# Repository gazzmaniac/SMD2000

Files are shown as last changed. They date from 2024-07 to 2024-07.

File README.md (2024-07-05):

# SMD2000
A mini-DTX version of the Amiga 2000 (motherboard)

## SMD 2000 Motherboard
This is the motherboard for the SMD2000 "BUSHFIRE" project, a mini-DTX sized Amiga 2000.
Official project information can be found at Amiga Retro Brisbane projects page:
https://www.amigaretro.com/projects/

## Licensing
Design is open source hardware.
1. Any and all derivative designs must also be open source.
2. No person, business, or other entity associated with this design shall be liable for any damages incurred by anyone as a result of using this design.  If you do not accept this condition do not build the project.
3. Free for private use by anyone.
4. Free for anyone to make for sale, except people associated with A1200.net keycaps.  You guys suck.
5. CERN Open Hardware Licence Version 2 - Strongly Reciprocal CERN-OHL-S) license applies, subject to conditions 1-4 above.
6. Any portions of this design from other projects shall be licensed according to their respective licenses if their licenses are not compatible with CERN-OHL-S or the conditions above.
7. All Other Rights Reserved.

## Requirements
To make this project work you also need to build an Agnus card and a CPU card.  They are documented separately.

Basic CPU card: https://github.com/gazzmaniac/SMD2000_cpu-card

2 MB Agnus card: https://github.com/gazzmaniac/SMD2000_Agnus2MB 

1 MB SMD Agnus card: https://github.com/gazzmaniac/SMD2000_Agnus_1MB 

1 MB TTH Agnus card: https://github.com/gazzmaniac/SMD2000_Agnus_1MB_TTH 

The SMD2000 project requires a donor Amiga, either an A500, A500+, A2000, or A600 plus a Gary.

## Useful Links
Bluster - in case you don't have a Buster IC (i.e. your donor machine is an A500):
https://github.com/LIV2/Bluster/tree/master
Bluster drop in replacement is not tested with the SMD2000 yet but there is no reason it will not work (the real Buster is confirmed working).

Open Video Hybrid - in case you don't have a Vidiot:
https://github.com/SukkoPera/OpenAmigaVideoHybrid

Latest RGB2HDMI software can be found at:
https://github.com/hoglet67/RGBtoHDMI/releases

## Notes and Eratta
Serial Port and Mouse Port are the same shape!  Now I know why Commodore used a 25 pin Serial port!  Be extra careful to not connect mouses to the serial port and serial devices to the mouse port otherwise there will be a release of magic smoke!  Recommend using DB9 protector for serial port e.g.: https://www.thingiverse.com/thing:2121877

### Power
Motherboard accepts a standard ATX PSU connector; both 20 and 24 pin versions work.  There is a header for a standard momentary push button switch which latches a 555 in bistable mode.  There is also a header to use a normal toggle switch or jumper to bypass the latching circuit and short PS_ON to GND.
The machine will happily run from a PicoPSU; the prototypes both ran from a PicoPSU-120-WI-25 powered from an old 19v laptop supply.  Just don't go connecting big loads like 5-1/4" hard disks to it.

### ROM
The SMD2000 has address lines for 1 MB or 2 MB ROMs.  Jumpers are present on the upper two address lines to switch between four 512 kb rom images (or two 1 MB images).

If using a Commodore rom or 27C400 eprom put it in the bottom of the socket, i.e. leave pins 1 and 42 on the socket empty (like on A500).  J519 & J520 do nothing in this scenario.

If using a 1 MB or 2 MB rom with multiple images you can switch between them using switches attached to CN519 & CN520; set J519 & J520 to 2-3.  Many users will want a switched Kickstart with KS1.3 and KS3.1/3.2; this can be achieved using a 27C800 with KS1.3 in the lower half and KS3.1 or 3.2 in the top half and connecting a switch to CN519.  You can switch up to four images (or a 1 MB image and two 512 kb images) using a 27C160 and CN520 as well.

If using a 1MB or 2MB custom rom set J519 & J520 to 1-2.

### LEDs
Extra LEDs have been added to the computer.  There are currently three ways to see the power LED, and two for the floppy drive LED (plus the LEDs on the floppy drives themselves).
Power LEDs:
Case: this is the same as in the A2000.  Populate Q302, R307, & C919.  If R308 is not populated the case LED will flash on and off instead of bright and dim when the Guru is about to meditate.  You can populate R308 if you want the LED to "dim" instead of switch off.  Commodore used a 200 ohm resistor in the A2000 and a 100 ohm resisitor on the A500 but optimal size will vary for your particular LED.
LED on motherboard: Populate Q360, R360, C360, & D360.  No "dim" option available.
LED on A500KBD port: fit Q361, R361, C361.  No "dim" option available.

### FDD LEDs
Floppy LEDs added same way as A500 (inverted _MTR0D).  Most users will not want to add a separate Floppy LED so these components are marked "Do Not Populate".
If using either of them populate the pull up resistor R363.
If using case floppy LED populate Q362, R362 & J360.
If using A500KBD port populate Q363 & R364.

NB the LEDs have changed since the final prototype.  The extra LED options (other than for the original case LED) are UNTESTED but there is no reason they will not work since it's simple copy paste.

### Other
Motherboard mounting holes had to be moved a little after the first prototype, and as a result the board was made 4 mm wider than "DTX" specification (on the slots side) but it still fits in the ML09 case.  Be careful if you intend to fit it in a tighter case.

## Fabrication Notes
Mouser part numbers for all components you can buy there are in the metadata for the symbols.  This has been exported as a CSV file, note this CSV file does not state which are Do Not Populate.

Use the interactive Bill of Materials for placing components, ibom.html.

The motherboard is expensive to make, being four layers.  I used JLCPCB, the cost was about $170 AUD for the minimum order of five boards, or a bit under $35 per board.  I chose green because it was the cheapest, they will do other colours for extra cost.  This includes an extra fee of $40 AUD due to the requirement for a 4-Wire Kelvin Test, due to the small size of the vias (this was mandatory from JLC).   Given the board is close to the limitations of JLCPCB I'm OK with that.  Don't specify the Kelvin test at initial checkout, they will add it later.  Even if you do specify it at checkout they will add it later again and you will pay for it twice (you can guess how I know this).  Even with the paying for two Kelvin tests it's way cheaper than PCBWaaaaaaay at USD 187 (about $280 AUD).

Assembly of the motherboard is a lot of work.  You can get JLC to partially assemble the board, I paid $284 AUD for partial assembly of two boards for the first prototype and $450 to partially assemble all five of the second prototype - that's most of the 0805 sized "birdseed" passives, about half the SMD ICs, and most of the headers.  That cost includes $30-40 worth of components on each board which you have to buy anyway, so it's actually a bargain if you consider it in relation to your hourly rate.  Get some mates together to share the upfront cost.  I think it's worthwhile unless you really, really like soldering birdseed.
I've added JLC's part number as a field in Kicad for many of the components so it shows up in their BOM tool, but it's not there for every component, and you will have to do some substitutions since the project was set up to be predominantly purchased from Mouser (I was going to hand solder it), some stuff is out of stock at JLC, and some stuff simply isn't available like the edge connectors.  When you use JLC's tool make sure you save a PDF copy of the BOM page so you know what not to buy from Mouser.  Also be aware if you want two sided assembly they will want you to add rails to the board, make sure they add a v cut so you can break them off after.  It's easier to specify this at the time of order.

This is a self-funded project and none of the companies mentioned have paid me anything.  This information is simply for your information, you can buy your PCB and component from whoever you like.

Finally, I had dramas with the tiny resistor packs every time I had to install them.  They're a real pain in the bum to solder by hand, and because JLC didn't have most of them in stock so I had to do it myself.  If your board doesn't work straight away, try reflowing all the resisitor packs.  If your mouse doesn't move check the resistor packs.  If you're cracking the shits it's probably because of the resistor packs.  You get the picture.  If you have a microscope it's really useful to check each one as you go.

## 3D Prints
An IO plate for the motherboard included.  Includes space for all the connectors on the back of the motherboard, plus parallel,  joystick, HDMI, and the Pi Button.

There is also a print for a bracket to hold a gotek and the power connector for a PicoPSU that fits in the spot for an SFX PSU.  It's tight, you'll probably need to change the right angle 34 pin and berg connectors for vertical connectors.

Photos of both are below, apologies for the print quality of the gotek bracket, I will update with a picture of a better quality print when I have time to print one.

FreeCad (v0.20.1) files are included so feel free to modify as needed.





## References
### Commodore Amiga References

Commodore Amiga A500/A2000 Technical Reference Manual.

Commodore schematics for A2000 Rev 4 & Rev 6.2, A500 Rev 6 & Rev 8 (A500+), and A1200 R1D4 schematics.  Scanned originals and amigawiki.org vector schematics referenced.

Coprocessor Expansion and 86 Pin Signals on Amiga Computers by Dave Haynie; this is presumably a Commodore document.

### Other References
DTX Mechanical Interface Specification rev 1.0.

ATX Specification v2.1 & v2.2.

Intel ISA Bus Specification and Application Notes.

Silverstone (r) ML109 case datasheet, www.silverstonetek.com.

### Other Projects incorporated into this one
#### RGB2HDMI
https://github.com/c0pperdragon/Amiga-Digital-Video

https://github.com/Bloodmosher/Amiga-VideoSlot-RGBtoHDMI

#### Video Output
https://www.pcbway.com/project/shareproject/Commodore_Amiga_DB23_RGB_External_Video_Buffer_V6_Compatible_with_GBS_8200_822_00cf763f.html

### Symbols
Symbols and footprints for most parts were downloaded from Mouser/Samacsys, and most were modified to make the schematics more readable.  Samacsys parts probably aren't covered by the Open Source license.  

Footprints and symbols for generic parts e.g. jumpers/headers use Kicad libraries. 

Most of the Amiga specific parts were modified from my SMD500 project.

### Datasheets
Links to datasheets are in the symbol metadata.

VGA Pinout Guide, https://pinoutguide.com/Video/VGA15_pinout.shtml.

M27C400 & M27C800 EPROM data sheets.

SPC Multicomp DSub9 to DSub25 adapter, http://www.farnell.com.

### Technical Guides
CTS Corporation Application Note: Crystal Basics, CTS Corporation.

A Guide to Debouncing by Jack G. Ganssle © 2004 The Ganssle Group.

555 timer in monostable mode https://todbot.com/blog/2010/01/02/momentary-button-as-onoff-toggle-using-555/.

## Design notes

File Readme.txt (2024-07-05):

SMD 2000 Motherboard
*-----------------------------------------------------------------------------*
This is the motherboard for the SMD2000 "BUSHFIRE" project, a mini-DTX sized Amiga 2000.
Official project information can be found at Amiga Retro Brisbane projects page:
https://www.amigaretro.com/projects/

Licensing
*-----------------------------------------------------------------------------*
LICENSING:
Design is open source hardware.
1. Any and all derivative designs must also be open source.
2. No person, business, or other entity associated with this design shall be liable for any damages incurred by anyone as a result of using this design.  If you do not accept this condition do not build the project.
3. Free for private use by anyone.
4. Free for anyone to make for sale, except people associated with A1200.net keycaps.  You guys suck.
5. CERN Open Hardware Licence Version 2 - Strongly Reciprocal CERN-OHL-S) license applies, subject to conditions 1-4 above.
6. Any portions of this design from other projects shall be licensed according to their respective licenses if their licenses are not compatible with CERN-OHL-S or the conditions above.
7. All Other Rights Reserved.

Requirements
*-----------------------------------------------------------------------------*
To make this project work you also need to build an Agnus card and a CPU card.  They are documented separately.

The SMD2000 project requires a donor Amiga, either an A500, A500+, A2000, or A600 plus a Gary.

Useful Links
*-----------------------------------------------------------------------------*
Bluster - in case you don't have a Buster IC (i.e. your donor machine is an A500):
https://github.com/LIV2/Bluster/tree/master
Bluster drop in replacement is not tested with the SMD2000 yet (the real Buster is).

Open Video Hybrid - in case you don't have a Vidiot:
https://github.com/SukkoPera/OpenAmigaVideoHybrid

Latest RGB2HDMI software can be found at:
https://github.com/hoglet67/RGBtoHDMI/releases

Notes and Eratta
*-----------------------------------------------------------------------------*
Serial Port and Mouse Port are the same shape!  Now I know why Commodore used a 25 pin Serial port!  Be extra careful to not connect mouses to the serial port and serial devices to the mouse port otherwise there will be release of magic smoke!  Recommend using DB9 protector for serial port e.g.: https://www.thingiverse.com/thing:2121877

ROM:
A2000 rom socket is a 40 pin socket and can take a 512 kB rom 
(27C400 equivalent).

The SMD2000 ROM socket is a 42 pin socket wired for a 1MB or 2 MB rom (e.g. 27C800).  Pins are offset by 1, since extra address lines wired to CPU Bus A19 & A20 (this is normal for EPROMs).  

If using a Commodore rom or 27C400 eprom put it in the bottom of the socket, i.e. leave pins 1 and 42 on the socket empty (like on A500).  J519 & J520 do nothing.

If using a 1 MB or 2 MB rom with multiple images you can switch them using switches attached to CN519 & CN520; set J519 & J520 to 2-3.  Many users want a Kickstart switch with KS1.3 and KS3.1/3.2; this can be achieved using a 27C800 with KS1.3 in the lower half and KS3.1 or 3.2 in the top half and connecting a switch to CN519.

If using a 1MB or 2MB custom rom set J519 & J520 to 1-2.

LEDs:
LEDs have been added to the computer.  There are currently three ways to see the power LED, and two for the floppy drive LED (plus the LEDs on the floppy drives themselves).
Power LEDs:
Case: this is the same as in the A2000.  Populate Q302, R307, & C919.  If R308 is not populated the case LED will flash on and off instead of bright and dim when the Guru is about to meditate.  You can populate R308 if you want the LED to "dim" instead of switch off.  Commodore used a 200 ohm resistor in the A2000 and a 100 ohm resisitor on the A500 but optimal size will vary for each LED.
LED on motherboard: Populate Q360, R360, C360, & D360.  No "dim" option available.
LED on A500KBD port: fit Q361, R361, C361.  No "dim" option available.

FDD LEDs:
Floppy LEDs added same way as A500 (inverted _MTR0D).  Most users will not want to add a Floppy LED to the case so these components are marked "Do Not Populate".
If using either of them populate the pull up resistor R363.
If using case floppy LED populate Q362, R362 & J360.
If using A500KBD port populate Q363 & R364.

NB the LEDs have changed since the prototype.  The extra LED options (other than for the case LED) are UNTESTED but there is no reason they will not work.

Motherboard mounting holes had to be moved a little after the first prototype, and as a result the board was made 4 mm wider than "DTX" specification but it still fits in the ML09 case.  Be careful if you intend to fit it in a tighter case.

Fabrication Notes
*-----------------------------------------------------------------------------*
Mouser part numbers for all components you can buy there are in the metadata for the symbols.  This has been exported as a CSV file, note this CSV file does not state which are Do Not Populate.

Use the interactive Bill of Materials for placing components, ibom.html.

The motherboard is expensive to make, being four layers.  I used JLCPCB, the cost was about $170 AUD for the minimum order of five boards, or a bit under $35 per board.  I chose green because it was the cheapest, they will do other colours for extra cost.  This includes an extra fee of $40 AUD due to the requirement for a 4-Wire Kelvin Test, due to the small size of the vias (this was mandatory from JLC).   Given the board is close to the limitations of JLCPCB I'm OK with that.  Even with the Kelvin testing it's less than half the price of PCBWaaaaaaay at USD 187.

Assembly of the motherboard is a lot of work.  You can get JLC to partially assemble the board, I paid $284 AUD for partial assembly of two boards for the first prototype and $450 to partially assemble all five of the second prototype - that's most of the 0805 sized "birdseed" passives, about half the SMD ICs, and most of the headers.  That cost includes $30-40 worth of components on each board which you have to buy anyway, so it's actually a bargain if you consider it in relation to your hourly rate.  Get some mates together to share the upfront cost.  I think it's worthwhile unless you really, really like soldering birdseed.
I've added JLC's part number as a field in Kicad for many of the components so it shows up in their BOM tool, but it's not there for every component, and you will have to do some substitutions since the project was set up to be predominantly purchased from Mouser (I was going to hand solder it), and some stuff simply isn't available like the edge connectors.  If you do use JLC's tool make sure you save a PDF copy of the BOM page so you know what not to buy from Mouser.  Also be aware if you want two sided assembly they will want you to add rails to the board, make sure they add a v cut so you can break them off after.  It's easier to specify this at the time of order.

This is a self-funded project and none of the companies mentioned have paid me anything.  This information is simply for your information, you can buy your PCB and component from whoever you like.

Finally, I had dramas with the tiny resistor packs every time I had to install them.  They're a real pain in the bum to solder by hand, and JLC didn't have most of them in stock so I had to do it myself.  If your board doesn't work straight away, try reflowing all the resisitor packs.  If your mouse doesn't move check the resistor packs.  If you're cracking the shits it's probably because of the resistor packs.  You get the picture.  If you have a microscope it's really useful to check each one as you go.

References
*-----------------------------------------------------------------------------*
Commodore Amiga References:
Commodore Amiga A500/A2000 Technical Reference Manual.
Commodore schematics for A2000 Rev 4 & Rev 6.2, A500 Rev 6 & Rev 8 (A500+), and A1200 R1D4 schematics.  Scanned originals and amigawiki.org rebuilds referenced.
Coprocessor Expansion and 86 Pin Signals on Amiga Computers by Dave Haynie; this is presumably a Commodore document.

Other References:
DTX Mechanical Interface Specification rev 1.0.
ATX Specification v2.1 & v2.2.
Intel ISA Bus Specification and Application Notes.
Silverstone (r) ML109 case datasheet, www.silverstonetek.com.

Other Projects incorporated into this one:
RGB2HDMI:
https://github.com/c0pperdragon/Amiga-Digital-Video
https://github.com/Bloodmosher/Amiga-VideoSlot-RGBtoHDMI
Video Output:
https://www.pcbway.com/project/shareproject/Commodore_Amiga_DB23_RGB_External_Video
  _Buffer_V6_Compatible_with_GBS_8200_822_00cf763f.html

Symbols:
Symbols and footprints for most parts were downloaded from Mouser/Samacsys, and most were modified to make the schematics more readable.  Samacsys parts probably aren't covered by the Open Source license.  Footprints and symbols for generic parts e.g. jumpers/headers use Kicad libraries. 

Datasheets:
Links to datasheets are in the symbol metadata.
VGA Pinout Guide, https://pinoutguide.com/Video/VGA15_pinout.shtml.
M27C400 & M27C800 EPROM data sheets.
SPC Multicomp DSub9 to DSub25 adapter, http://www.farnell.com.

Technical Guides:
CTS Corporation Application Note: Crystal Basics, CTS Corporation.
A Guide to Debouncing by Jack G. Ganssle © 2004 The Ganssle Group.
555 timer in monostable mode https://todbot.com/blog/2010/01/02/momentary-button-as-onoff-toggle-using-555/.

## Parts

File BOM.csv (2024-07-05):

Additional Parts (Not Mouser). Delete this section for upload to Mouser
Reference | Value | Footprint | Datasheet | Comment | Description | EU_RoHS_Compliance | Height | LCSC Part # | Manufacturer_Name | Manufacturer_Part_Number | Modified | Mouser Part Number | Mouser Price/Stock | Qty
HY200 | VIDIOT |  |  |  | Video Hybrid |  |  |  | MOS Technology | 390229-0x |  |  |  | 1
U102 | GARY |  |  |  | 5719 |  |  |  | MOS Technology | 318072-01 |  |  |  | 1
U200 | PAULA |  |  |  | 8364R7 |  |  |  | MOS Technology | 252127-02 |  |  |  | 1
U201 | DENISE |  |  |  | 8362/8373 |  |  |  | MOS Technology | 252126-02/390433-02 |  |  |  | 1
U800 | BUSTER |  |  |  | 5731 |  |  |  | MOS Technology | 318075-02 |  |  |  | 1
U300, U301 | CIA |  |  |  | 8520A-1 |  |  |  | MOS Technology | 391078-0x |  |  |  | 2
U500 | ROM |  |  |  | 27C400 |  |  |  | Various |  |  |  |  | 1
U801 | MSM6242 |  | https://pdf1.alldatasheet.com/datasheet-pdf/download/11259/OKI/MSM6242B.html |  | Real Time Clock |  |  |  | OKI | MSM6242 |  |  |  | 1
Reference | Value | Footprint | Datasheet | Comment | Description | EU_RoHS_Compliance | Height | LCSC Part # | Manufacturer_Name | Manufacturer_Part_Number | Modified | Mouser Part Number | Mouser Price/Stock | Qty
BT800 | CR1220 | SMD2000_Footprints:S8411-45R_1 | https://cdn.harwin.com/pdfs/S8411R.pdf |  |  |  |  | C9900008699 | Harwin | S8411-45R |  | 855-S8411-45R | https://www.mouser.co.uk/ProductDetail/Harwin/S8411-45R?qs=Qom7kyPojXY6B0JhnWxDgQ%3D%3D | 1
C101, C222, C223, C402-C406, C408, C412, C420-C422, C471 | 47 uF | SMD2000_Footprints:EEE0GA101SR | http://industrial.panasonic.com/cdbs/www-data/pdf/RDE0000/ABA0000C1142.pdf |  | Cap Aluminum Lytic 47uF 16V 20% (5 X 5.4mm) SMD 39mA 1000h 85C Automotive T/R |  | 6.5 | C178500 | Panasonic | EEE-1CA470WAR |  | 667-EEE-1CA470WAR | https://www.mouser.co.uk/ProductDetail/Panasonic/EEE-1CA470WAR?qs=d1CqaRUMZD%2FiYn4JMv7QWw%3D%3D | 14
C102-C108, C200, C202, C203, C205, C206, C230, C234, C240, C244, C300-C303, C305, C351, C360, C361, C450, C451, C600-C605, C607, C800, C802-C805, C812, C815, C900, C901, C903, C906, C909, C910, C915, C916, C918, C919, C1201-C1205, C1251 | 0.1 uF | Capacitor_SMD:C_0805_2012Metric_Pad1.18x1.45mm_HandSolder | http://datasheets.avx.com/X7RDielectric.pdf |  | 0805 X7R ceramic capacitor,100nF 50V AVX 0805 Standard 100nF Ceramic Multilayer Capacitor, 50 V dc, +125degC, X7R Dielectric, /-10% SMD |  | 0.94 | C123316 | AVX | 08055C104KAT2A |  | 581-08055C104K | https://www.mouser.co.uk/ProductDetail/AVX/08055C104KAT2A?qs=2ujN4bDBNE9mJvapP%252BjopA%3D%3D | 56
C201, C219-C221, C500 | 0.22uF | Capacitor_SMD:C_0805_2012Metric_Pad1.18x1.45mm_HandSolder | http://datasheets.avx.com/X7RDielectric.pdf |  | 0805 X7R ceramic capacitor,0.22uF 50V AVX 0805 Standard 100nF Ceramic Multilayer Capacitor, 50 V dc, +125degC, X7R Dielectric, /-10% SMD |  | 0.94 |  | AVX | 08053C224K4T2A |  | 581-08053C224K4T2A | https://au.mouser.com/ProductDetail/KYOCERA-AVX/08053C224K4T2A?qs=MaXcIz3NWU%252Bt3orNT4zafw%3D%3D | 5
C204, C401, C407, C409, C413, C472 | 0.01 uF | Capacitor_SMD:C_0805_2012Metric_Pad1.18x1.45mm_HandSolder | https://componentsearchengine.com/Datasheets/1/0805YC473KAT2A.pdf |  | Capacitor 0805 0.01UF +/-10% 16V |  |  |  | AVX | 0805YC103KAT4A |  | 581-0805YC103KAT4A | https://au.mouser.com/ProductDetail/KYOCERA-AVX/0805YC103KAT4A?qs=0j3vzYx9OgSOvplKldyO1Q%3D%3D | 6
C210-C213 | 0.047 uF | Capacitor_SMD:C_0805_2012Metric_Pad1.18x1.45mm_HandSolder | https://componentsearchengine.com/Datasheets/1/0805YC473KAT2A.pdf |  | Capacitor 0805 0.047UF +/-10% 16V |  |  |  | AVX | 0805YC473KAT2A |  | 581-0805YC473K | https://www.mouser.com/Search/Refine.aspx?Keyword=581-0805YC473K | 4
C214, C225, C226, C912 | 470 uF | SMD2000_Footprints:EEE-1EA471UAP | http://industrial.panasonic.com/cdbs/www-data/pdf/RDE0000/ABA0000C1142.pdf |  | PANASONIC - EEE-1EA471UAP - SMD Aluminum Electrolytic Capacitor, Radial Can - SMD, 470 F, 25 V, S Series, 2000 hours @ 85C |  |  | C336541 | Panasonic | EEE-1EA471UAP |  | 667-EEE-1EA471UAP | https://www.mouser.co.uk/ProductDetail/Panasonic/EEE-1EA471UAP?qs=d1CqaRUMZD8omPdhpIp4IQ%3D%3D | 4
C224, C415, C811 | 4.7 uF | SMD2000_Footprints:EEE1AA220WR | http://industrial.panasonic.com/cdbs/www-data/pdf/RDE0000/ABA0000C1142.pdf |  | Cap Aluminum Lytic 4.7uF 50V 20% (4 X 5.4mm) SMD 18mA 1000h 85C Automotive T/R |  | 5.5 | C336729 | Panasonic | EEE-1HA4R7WAR |  | 667-EEE-1HA4R7WAR | https://au.mouser.com/ProductDetail/Panasonic/EEE-1HA4R7WAR?qs=d1CqaRUMZD%2FQfKz6dMeWdw%3D%3D | 3
C231, C241 | 6800 pF | Capacitor_SMD:C_0805_2012Metric_Pad1.18x1.45mm_HandSolder |  |  | Multilayer Ceramic Capacitors MLCC - SMD/SMT 50V 6800pF X7R 0805 10% Tol |  | 0.94 | C597425 | AVX | 08055C682KAT2A |  | 581-08055C682K | https://www.mouser.co.uk/ProductDetail/AVX/08055C682KAT2A?qs=wrGVMSTfBskTBQdegZmEHA%3D%3D | 2
C232, C242 | 3900 pF | Capacitor_SMD:C_0805_2012Metric_Pad1.18x1.45mm_HandSolder | https://www.arrow.com/en/products/08055c392kat2a/avx |  | Cap Ceramic 0.0039uF 50V X7R 10% Pad SMD 0805 125C T/R |  | 0.94 | C2181318 | AVX | 08055C392KAT2A |  | 581-08055C392K | https://www.mouser.co.uk/ProductDetail/AVX/08055C392KAT2A?qs=FObrNSbSblfLejKoKFqNfg%3D%3D | 2
C233, C243, C813, C814, C1206 | 22 uF | SMD2000_Footprints:EEE0GA101SR | https://componentsearchengine.com/Datasheets/1/EEE-1VA220WAR.pdf |  | Cap Aluminum Lytic 22uF 35V 20% (5 X 5.4mm) SMD 36mA 1000h 85C Automotive T/R |  | 6.5 | C336455 | Panasonic | EEE-1VA220WAR |  | 667-EEE-1VA220WAR | https://www.mouser.com/Search/Refine.aspx?Keyword=667-EEE-1VA220WAR | 5
C259-C261, C904, C905, C907, C914, C920 | 100 pF | Capacitor_SMD:C_0805_2012Metric_Pad1.18x1.45mm_HandSolder | https://componentsearchengine.com/Datasheets/1/06031A100FAT2A.pdf |  | 0805 C0G ceramic capacitor,100pF 50V AVX 0805 Standard 100pF Ceramic Multilayer Capacitor, 50 V dc C0G Dielectric +/-5% SMD |  | 0.94 | C2167403 | AVX | 08055A101JAT2A |  | 581-08055A101J | https://www.mouser.co.uk/ProductDetail/AVX/08055A101JAT2A?qs=o9qE778H9QGBR%2FfSpI%2FCIw%3D%3D | 8
C350 | 1 uF | Capacitor_SMD:C_0805_2012Metric_Pad1.18x1.45mm_HandSolder | https://componentsearchengine.com/Datasheets/2/08055C105KAT2A.pdf |  | MLCC Capacitor 1uF 0805 X7R 10% 50V AVX 0805 Standard 1uF Ceramic Multilayer Capacitor, 50 V, +125C, X7R Dielectric, +/-10% |  | 1.4 | C2167382 | AVX | 08055C105KAT2A |  | 581-08055C105KAT2A | https://www.mouser.co.uk/ProductDetail/AVX/08055C105KAT2A?qs=2ujN4bDBNE9BNQHBgLvfKA%3D%3D | 1
C400, C416, C470 | 220 uF | SMD2000_Footprints:EEHZT1E331UP | https://componentsearchengine.com/Datasheets/1/EEE-1EA221UAP.pdf |  | Panasonic 220F 25V dc Aluminium Electrolytic Capacitor, Surface Mount 8 x 10.2mm +85C 8mm 10.2mm |  | 10.8 | C336328 | Panasonic | EEE-1EA221UAP |  | 667-EEE-1EA221UAP | https://www.mouser.com/Search/Refine.aspx?Keyword=667-EEE-1EA221UAP | 3
C452 | 4.7 uF | Capacitor_SMD:C_0805_2012Metric_Pad1.18x1.45mm_HandSolder | https://au.mouser.com/datasheet/2/40/KGM_X7R-3223212.pdf |  | Multilayer Ceramic Capacitors MLCC - SMD/SMT KGM21AR71E475KU NEW GLOBAL PN 25V 4.7uF X7R 0805 10% |  | 1.4 |  | AVX | 08053C475KAT2A |  | 581-08053C475KAT2A | https://au.mouser.com/ProductDetail/KYOCERA-AVX/08053C475KAT2A?qs=ZBeOGGPQgEF8AwTFFr2g8w%3D%3D | 1
C460, C461 | 10 uF | SMD2000_Footprints:EEE1AA220WR | http://industrial.panasonic.com/cdbs/www-data/pdf/RDE0000/ABA0000C1142.pdf |  | PANASONIC ELECTRONIC COMPONENTS - EEE1EA100WAR - CAP, ALU ELEC, 10UF, 25V, SMD |  | 5.5 | C336730 | Panasonic | EEE-1EA100WAR |  | 667-EEE-1EA100WAR | https://www.mouser.co.uk/ProductDetail/Panasonic/EEE-1EA100WAR?qs=d1CqaRUMZD8IzJai8yeTmQ%3D%3D | 2
C617, C619-C633, C635, C637, C639, C641, C645, C647, C649-C652, C654, C655, C657-C674, C678 | 1000 pF | Capacitor_SMD:C_0805_2012Metric_Pad1.18x1.45mm_HandSolder | https://spicat.kyocera-avx.com/product/mlcc/chartview/08055C102KAT2A/DataSheet/X7R |  | 0805 X7R ceramic capacitor,1nF 50V AVX 0805 Standard 1nF Ceramic Multilayer Capacitor, 50 V dc, +125C, X7R Dielectric, +/-10% SMD |  | 0.94 | C2167121 | AVX | 08055C102KAT2A |  | 581-08055C102K | https://www.mouser.co.uk/ProductDetail/AVX/08055C102KAT2A?qs=m1SnNO%2FH6BdUeLRSfRyJzA%3D%3D | 47
C810 | 18 pF | Capacitor_SMD:C_0805_2012Metric_Pad1.18x1.45mm_HandSolder | https://componentsearchengine.com/Datasheets/1/08055A180KAT4A.pdf |  | Capacitor, 0805 18pF +/-10% 50V |  |  | C2209310 | AVX | 08055A180KAT4A |  | 581-08055A180KAT4A | https://www.mouser.com/Search/Refine.aspx?Keyword=581-08055A180KAT4A | 1
C908, C913, C1252 | 47 pF | Capacitor_SMD:C_0805_2012Metric_Pad1.18x1.45mm_HandSolder | https://au.mouser.com/datasheet/2/40/C0GNP0_KGM-3216332.pdf |  | Capacitor, 0805 47pF +/-10% 50V |  |  | C2209271 | AVX | 08055A470KAT4A |  | 581-08055A470KAT4A | https://au.mouser.com/ProductDetail/KYOCERA-AVX/08055A470KAT4A?qs=puY0Jq7LBATPo1cS1%252BxjXg%3D%3D | 3
CE218 | 0.22uF | Capacitor_SMD:C_0805_2012Metric_Pad1.18x1.45mm_HandSolder | http://datasheets.avx.com/X7RDielectric.pdf |  | 0805 X7R ceramic capacitor,0.22uF 50V AVX 0805 Standard 100nF Ceramic Multilayer Capacitor, 50 V dc, +125degC, X7R Dielectric, /-10% SMD |  | 0.94 |  | AVX | 08053C224K4T2A |  | 581-08053C224K4T2A | https://au.mouser.com/ProductDetail/KYOCERA-AVX/08053C224K4T2A?qs=MaXcIz3NWU%252Bt3orNT4zafw%3D%3D | 1
CE230-CE237 | 6800 pF | Capacitor_SMD:C_0805_2012Metric_Pad1.18x1.45mm_HandSolder |  |  | Multilayer Ceramic Capacitors MLCC - SMD/SMT 50V 6800pF X7R 0805 10% Tol |  | 0.94 | C597425 | AVX | 08055C682KAT2A |  | 581-08055C682K | https://www.mouser.co.uk/ProductDetail/AVX/08055C682KAT2A?qs=wrGVMSTfBskTBQdegZmEHA%3D%3D | 8
CE238-CE243, CE327, CE329-CE331 | 470 pF | Capacitor_SMD:C_0805_2012Metric_Pad1.18x1.45mm_HandSolder | http://datasheets.avx.com/C0GNP0-Dielectric.pdf |  | AVX 0805 Standard 470pF Ceramic Multilayer Capacitor, 50 V dc, +125 |  | 0.94 |  | AVX | 08055A471JAT2A |  | 581-08055A471J | https://www.mouser.co.uk/ProductDetail/AVX/08055A471JAT2A?qs=puY0Jq7LBATs%2FWzMvXMJew%3D%3D | 10
CE300-CE309, CE326, CE328, CE333, CE335-CE338 | 100 pF | Capacitor_SMD:C_0805_2012Metric_Pad1.18x1.45mm_HandSolder | https://componentsearchengine.com/Datasheets/1/06031A100FAT2A.pdf |  | 0805 C0G ceramic capacitor,100pF 50V AVX 0805 Standard 100pF Ceramic Multilayer Capacitor, 50 V dc C0G Dielectric +/-5% SMD |  | 0.94 | C2167403 | AVX | 08055A101JAT2A |  | 581-08055A101J | https://www.mouser.co.uk/ProductDetail/AVX/08055A101JAT2A?qs=o9qE778H9QGBR%2FfSpI%2FCIw%3D%3D | 17
CE310, CE325 | 0.01 uF | Capacitor_SMD:C_0805_2012Metric_Pad1.18x1.45mm_HandSolder | https://componentsearchengine.com/Datasheets/1/0805YC473KAT2A.pdf |  | Capacitor 0805 0.01UF +/-10% 16V |  |  |  | AVX | 0805YC103KAT4A |  | 581-0805YC103KAT4A | https://au.mouser.com/ProductDetail/KYOCERA-AVX/0805YC103KAT4A?qs=0j3vzYx9OgSOvplKldyO1Q%3D%3D | 2
CN101 | AGNUS BOARD | Connector_PinHeader_2.54mm:PinHeader_2x40_P2.54mm_Vertical | https://au.mouser.com/datasheet/2/1/29b4744faceffeb20158dc55b88f3486ed430ebb-2951472.pdf |  |  |  |  |  | 3M Electronic Solutions Division | 2380-5121TG |  | 517-5121TG | https://au.mouser.com/ProductDetail/3M-Electronic-Solutions-Division/2380-5121TG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 | 1
CN201 | MOUSE | SMD2000_Footprints:L717SDE09PA4CH3F | https://cdn.amphenol-cs.com/media/wysiwyg/files/drawing/l717sdxxxpa4ch3f.pdf |  | Dsub, Stamped Signal 3A, Right Angle PCB Through Hole, FP=8.08mm (0.318in), Row Pitch 2.84mm, 09 Pin, Flash Gold, Bright Tin Shell+Grounding Dimples, M3 Front Screwlock, Ground Tab with Boardlock |  | 12.85 |  | Amphenol Communications Solutions | L717SDE09PA4CH3F |  | 523-L717SDE09PA4CH3F | https://au.mouser.com/ProductDetail/Amphenol-Commercial-Products/L717SDE09PA4CH3F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 | 1
CN204 | AUDIO | SMD2000_Footprints:RCJ2221 | https://www.cuidevices.com/product/resource/digikeypdf/rcj-22xx.pdf |  | Conn RCA RCP 2 POS 4mm Solder RA Thru-Hole 3 Terminal 2 Port |  | 27.4 | C4991581 | CUI Devices | RCJ-2223 |  | 490-RCJ-2223 | https://www.mouser.co.uk/ProductDetail/CUI-Devices/RCJ-2223?qs=WyjlAZoYn50wV0WbOL8WfA%3D%3D | 1
CN250 | JOYSTICK | SMD2000_Footprints:PinHeader_2x05_P2.54mm_Vertical_Top_Bottom | https://cdn.amphenol-cs.com/media/wysiwyg/files/documentation/datasheet/boardwiretoboard/bwb_bergstik.pdf |  |  |  |  |  | Amphenol FCI | 67997-410HLF |  | 649-67997-410HLF | https://au.mouser.com/ProductDetail/Amphenol-FCI/67997-410HLF?qs=EEeFj3a206OMu9AFYw1RTQ%3D%3D | 1
CN251 | MOUSE | SMD2000_Footprints:PinHeader_2x05_P2.54mm_Vertical_Top_Bottom | https://cdn.amphenol-cs.com/media/wysiwyg/files/documentation/datasheet/boardwiretoboard/bwb_bergstik.pdf |  |  |  |  |  | Amphenol FCI | 67997-410HLF |  | 649-67997-410HLF | https://au.mouser.com/ProductDetail/Amphenol-FCI/67997-410HLF?qs=EEeFj3a206OMu9AFYw1RTQ%3D%3D | 1
CN300 | KEYBOARD | SMD2000_Footprints:SDF50J | https://www.cuidevices.com/product/resource/sdf-j.pdf |  | Conn Circular DIN SKT 5 POS Solder RA Thru-Hole 5 Terminal 1 Port |  | 21.5 |  | CUI Devices | SDF-50J |  | 490-SDF-50J | https://www.mouser.co.uk/ProductDetail/CUI-Devices/SDF-50J?qs=WyjlAZoYn50bYX9%252BKt7ljQ%3D%3D | 1
CN301 | PARALLEL | Connector_PinHeader_2.54mm:PinHeader_2x13_P2.54mm_Vertical | https://cdn.amphenol-cs.com/media/wysiwyg/files/documentation/datasheet/boardwiretoboard/bwb_bergstik.pdf |  |  |  |  |  | Amphenol FCI | 67996-426HLF |  | 649-67996-426HLF | https://au.mouser.com/ProductDetail/Amphenol-FCI/67996-426HLF?qs=QKvFUfBIyQJ%2F0pFrKp20QQ%3D%3D | 1
CN303 | FLOPPY | Connector_PinHeader_2.54mm:PinHeader_2x17_P2.54mm_Vertical | https://cdn.amphenol-cs.com/media/wysiwyg/files/documentation/datasheet/boardwiretoboard/bwb_bergstik.pdf |  |  |  |  |  | Amphenol FCI | 67996-434HLF |  | 649-67996-434HLF | https://au.mouser.com/ProductDetail/Amphenol-FCI/67996-434HLF?qs=QKvFUfBIyQKJg0WZsSdJsw%3D%3D | 1
CN305 | SERIAL | SMD2000_Footprints:L717SDE09PA4CH3F | https://cdn.amphenol-cs.com/media/wysiwyg/files/drawing/l717sdxxxpa4ch3f.pdf |  | Dsub, Stamped Signal 3A, Right Angle PCB Through Hole, FP=8.08mm (0.318in), Row Pitch 2.84mm, 09 Pin, Flash Gold, Bright Tin Shell+Grounding Dimples, M3 Front Screwlock, Ground Tab with Boardlock |  | 12.85 |  | Amphenol Communications Solutions | L717SDE09PA4CH3F |  | 523-L717SDE09PA4CH3F | https://au.mouser.com/ProductDetail/Amphenol-Commercial-Products/L717SDE09PA4CH3F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 | 1
CN306 | POWER LED | Connector_PinHeader_2.54mm:PinHeader_1x03_P2.54mm_Vertical | https://cdn.amphenol-cs.com/media/wysiwyg/files/documentation/datasheet/boardwiretoboard/bwb_econostik_254headers.pdf |  | Headers & Wire Housings 2.54MM VT ECONOSTIK HDR |  |  |  | Amphenol FCI | 10129378-903001BLF |  | 649-1012937890301BLF | https://au.mouser.com/ProductDetail/Amphenol-FCI/10129378-903001BLF?qs=0lQeLiL1qybuYTJnitumiA%3D%3D | 1
CN350 | A500KBD | Connector_PinHeader_2.54mm:PinHeader_1x08_P2.54mm_Vertical | https://cdn.amphenol-cs.com/media/wysiwyg/files/documentation/datasheet/boardwiretoboard/bwb_econostik_254headers.pdf |  | Headers & Wire Housings ECONOSTIK HEADER SR VT TH 1X8 |  |  |  | Amphenol FCI | 10129378-908001BLF |  | 649-1012937890801BLF | https://au.mouser.com/ProductDetail/Amphenol-FCI/10129378-908001BLF?qs=0lQeLiL1qybDtVkZc9V5DA%3D%3D | 1
CN400 | POWER | SMD2000_Footprints:44206-0007_1 | https://www.molex.com/pdm_docs/sd/442060001_sd.pdf |  | Mini-Fit Jr. Header, Dual Row, Vertical, with 11.90mm Locking Ramp, 24 Circuits, with Peg 2 Snap-in Plastic Peg |  | 12.8 |  | Molex | 44206-0007 |  | 538-44206-0007 | https://www.mouser.co.uk/ProductDetail/Molex/44206-0007?qs=g5f4E6w8l8gzEjxCgQ0R8g%3D%3D | 1
CN450 | POWERSW | Connector_PinHeader_2.54mm:PinHeader_1x03_P2.54mm_Vertical | https://cdn.amphenol-cs.com/media/wysiwyg/files/documentation/datasheet/boardwiretoboard/bwb_econostik_254headers.pdf |  | Headers & Wire Housings 2.54MM VT ECONOSTIK HDR |  |  |  | Amphenol FCI | 10129378-903001BLF |  | 649-1012937890301BLF | https://au.mouser.com/ProductDetail/Amphenol-FCI/10129378-903001BLF?qs=0lQeLiL1qybuYTJnitumiA%3D%3D | 1
CN451-CN453 | 3.3 v | Connector_PinHeader_2.54mm:PinHeader_1x03_P2.54mm_Vertical | https://cdn.amphenol-cs.com/media/wysiwyg/files/documentation/datasheet/boardwiretoboard/bwb_econostik_254headers.pdf |  | Headers & Wire Housings 2.54MM VT ECONOSTIK HDR |  |  |  | Amphenol FCI | 10129378-903001BLF |  | 649-1012937890301BLF | https://au.mouser.com/ProductDetail/Amphenol-FCI/10129378-903001BLF?qs=0lQeLiL1qybuYTJnitumiA%3D%3D | 3
CN519, CN520 | A19_ROMSW | Connector_PinHeader_2.54mm:PinHeader_1x02_P2.54mm_Vertical | https://cdn.amphenol-cs.com/media/wysiwyg/files/documentation/datasheet/boardwiretoboard/bwb_bergstik.pdf |  |  |  |  |  | Amphenol FCI | 67996-400HLF |  | 649-67996-400HLF | https://au.mouser.com/ProductDetail/Amphenol-FCI/67996-400HLF?qs=cpLrBgdhsoHypZ881pDXnQ%3D%3D | 2
CN600 | CPU Card | SMD2000_Footprints:TE_1-5530843-0 | https://www.te.com/commerce/DocumentDelivery/DDEController?Action=srchrtrv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 | 1-5530843-0 |  | Compliant |  | C4693071 | TE Connectivity / AMP | 1-5530843-0 |  | 571-1-5530843-0 | https://au.mouser.com/ProductDetail/TE-Connectivity-AMP/1-5530843-0?qs=uJX40y%252BSWqjthdq8B1k%252BaA%3D%3D | 1
CN601 | Zorro | SMD2000_Footprints:TE_5645235-3 | https://www.te.com/commerce/DocumentDelivery/DDEController?Action=srchrtrv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 | 5645235-3 |  | Compliant |  | C4659716 | TE Connectivity / AMP | 5645235-3 |  | 571-5645235-3 | https://au.mouser.com/ProductDetail/TE-Connectivity-AMP/5645235-3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 | 1
CN606 | IPL | Connector_PinHeader_2.54mm:PinHeader_1x04_P2.54mm_Vertical | https://cdn.amphenol-cs.com/media/wysiwyg/files/documentation/datasheet/boardwiretoboard/bwb_econostik_254headers.pdf |  | Headers & Wire Housings ECONOSTIK HEADER SR VT TH 1X4 |  |  |  | Amphenol FCI | 10129378-904002BLF |  | 649-1012937890402BLF | https://au.mouser.com/ProductDetail/Amphenol-FCI/10129378-904002BLF?qs=0lQeLiL1qyaw2kaC5TTjqQ%3D%3D | 1
CN650 | CPU_EXT | Connector_PinHeader_2.54mm:PinHeader_1x07_P2.54mm_Vertical | https://cdn.amphenol-cs.com/media/wysiwyg/files/documentation/datasheet/boardwiretoboard/bwb_econostik_254headers.pdf |  | Headers & Wire Housings ECONOSTIK HEADER SR VT TH 1X7 |  |  |  | Amphenol FCI | 10129378-907003BLF |  | 649-1012937890703BLF | https://au.mouser.com/ProductDetail/Amphenol-FCI/10129378-907003BLF?qs=0lQeLiL1qyaQcjBpJILP3A%3D%3D | 1
CN950 | FLOPPY_EXT | Connector_PinHeader_2.54mm:PinHeader_1x04_P2.54mm_Vertical | https://cdn.amphenol-cs.com/media/wysiwyg/files/documentation/datasheet/boardwiretoboard/bwb_econostik_254headers.pdf |  | Headers & Wire Housings ECONOSTIK HEADER SR VT TH 1X4 |  |  |  | Amphenol FCI | 10129378-904002BLF |  | 649-1012937890402BLF | https://au.mouser.com/ProductDetail/Amphenol-FCI/10129378-904002BLF?qs=0lQeLiL1qyaw2kaC5TTjqQ%3D%3D | 1
CN1201 | 15 Pin Video | SMD2000_Footprints:1563315E | https://www.mouser.ch/datasheet/2/209/KC-301179-193296.pdf |  |  |  | 12.5 |  | Kobiconn | 156-3315-E |  | 156-3315-E | https://www.mouser.co.uk/ProductDetail/Kobiconn/156-3315-E?qs=RC2ne4458IJMP%252Bd8Z1f5lQ%3D%3D | 1
CN1202 | ANALOGUE VIDEO | Connector_PinHeader_2.54mm:PinHeader_1x08_P2.54mm_Vertical | https://cdn.amphenol-cs.com/media/wysiwyg/files/documentation/datasheet/boardwiretoboard/bwb_econostik_254headers.pdf |  | Headers & Wire Housings ECONOSTIK HEADER SR VT TH 1X8 |  |  |  | Amphenol FCI | 10129378-908001BLF |  | 649-1012937890801BLF | https://au.mouser.com/ProductDetail/Amphenol-FCI/10129378-908001BLF?qs=0lQeLiL1qybDtVkZc9V5DA%3D%3D | 1
CN1250 | Raspberry Pi Zero | SMD2000_Footprints:PinSocket_2x20_P2.54mm_Vertical | https://au.mouser.com/datasheet/2/813/DS-16763-2_X_20_Pin_Extended_GPIO_Header_-_Female_-1880586.pdf |  |  |  |  |  | Spark-Fun | PRT-16763 |  | 474-PRT-16763 | https://au.mouser.com/ProductDetail/SparkFun/PRT-16763?qs=W%2FMpXkg%252BdQ5xeCq%2FGKjnlQ%3D%3D | 1
CN1251, CN1252 | PI BTN | Connector_PinHeader_2.54mm:PinHeader_1x02_P2.54mm_Vertical | https://cdn.amphenol-cs.com/media/wysiwyg/files/documentation/datasheet/boardwiretoboard/bwb_bergstik.pdf |  |  |  |  |  | Amphenol FCI | 67996-400HLF |  | 649-67996-400HLF | https://au.mouser.com/ProductDetail/Amphenol-FCI/67996-400HLF?qs=cpLrBgdhsoHypZ881pDXnQ%3D%3D | 2
D300, D353, D800-D802 | 1N4148WS | SMD2000_Footprints:SODFL2512X90N |  |  | ON Semiconductor Switching Diode, 300mA 75V, 2-Pin SOD-323 1N4148WS |  | 0.9 | C118873 | onsemi | 1N4148WS |  | 512-1N4148WS | https://www.mouser.co.uk/ProductDetail/onsemi-Fairchild/1N4148WS?qs=2%2FYqgE%252BHg%252BKBrKZlAsMLhw%3D%3D | 5
D360 | BLUE | SMD2000_Footprints:LEDC2012X80N | https://katalog.we-online.com/led/datasheet/150080BS75000.pdf |  | LED,Wurth Elektronik,150080BS75000 Wurth Elektronik 150080BS75000, WL-SMCW Series Blue LED, 470 nm 2012 (0805) Clear, Rectangle Lens SMD package |  | 0.8 | C9900019499 | Wurth Elektronik | 150080BS75000 |  | 710-150080BS75000 | https://www.mouser.co.uk/ProductDetail/Wurth-Elektronik/150080BS75000?qs=2kOmHSv6VfT2tBo3UPVqAQ%3D%3D | 1
D803 | BAT54WS | SMD2000_Footprints:SOD2513X120N | https://au.mouser.com/datasheet/2/115/DIOD_S_A0004140728_1-2542383.pdf |  | Diodes Inc BAT54WS-7-F, SMT Schottky Switching Diode, 30V 200mA, 5ns, 2-Pin SOD-323 |  | 1.2 | C124205 | Diodes Inc. | BAT54WS-7-F |  | 621-BAT54WS-F | https://www.mouser.co.uk/ProductDetail/Diodes-Incorporated/BAT54WS-7-F?qs=BJo294706GxanB6a%2FKrrdw%3D%3D | 1
E1-E4 | MountingHole_Pad | MountingHole:MountingHole_4mm_Pad_Via | ~ |  |  |  |  |  |  |  |  |  |  | 4
EMI200, EMI229 | 100 pF | SMD2000_Footprints:W2H11A10184T1F | https://au.mouser.com/datasheet/2/40/MultilayerFeedthruCapacitorsAndArrays-3161979.pdf |  |  |  | 1.14 |  | Kyocera AVX | W2H11A10184T1F |  | 581-W2H11A10184T1F | https://www.mouser.com/Search/Refine.aspx?Keyword=581-W2H11A10184T1F | 2
FB102, FB301-FB303, FB401, FB907, FB1201-FB1205 | FB | Resistor_SMD:R_1206_3216Metric_Pad1.30x1.75mm_HandSolder | https://fair-rite.com/product/chip-beads-2512061517y3/#select:onepart |  |  |  |  | C6401928 | Fair-Rite | 2512061217Y5 |  | 623-2512061217Y5 | https://au.mouser.com/ProductDetail/Fair-Rite/2512061217Y5?qs=paL1wOLBYNdLzI%2FVPVZ0Rg%3D%3D | 11
HY200 | VIDIOT | Connector_PinHeader_2.54mm:PinHeader_1x22_P2.54mm_Vertical |  |  |  |  |  |  |  |  |  |  |  | 1
J200 | LPEN | Jumper:SolderJumper-3_P1.3mm_Bridged12_Pad1.0x1.5mm | ~ |  |  |  |  |  |  |  |  |  |  | 1
J300 | TICK | Jumper:SolderJumper-2_P1.3mm_Bridged_RoundedPad1.0x1.5mm | ~ |  |  |  |  |  |  |  |  |  |  | 1
J301 | DF1: | Connector_PinHeader_2.54mm:PinHeader_1x02_P2.54mm_Vertical | https://cdn.amphenol-cs.com/media/wysiwyg/files/documentation/datasheet/boardwiretoboard/bwb_bergstik.pdf |  |  |  |  |  | Amphenol FCI | 67996-400HLF |  | 649-67996-400HLF | https://au.mouser.com/ProductDetail/Amphenol-FCI/67996-400HLF?qs=cpLrBgdhsoHypZ881pDXnQ%3D%3D | 1
J351 | RESET | Connector_PinHeader_2.54mm:PinHeader_1x02_P2.54mm_Vertical | https://cdn.amphenol-cs.com/media/wysiwyg/files/documentation/datasheet/boardwiretoboard/bwb_bergstik.pdf |  |  |  |  |  | Amphenol FCI | 67996-400HLF |  | 649-67996-400HLF | https://au.mouser.com/ProductDetail/Amphenol-FCI/67996-400HLF?qs=cpLrBgdhsoHypZ881pDXnQ%3D%3D | 1
J360 | FLOPPYLED | Connector_PinHeader_2.54mm:PinHeader_1x02_P2.54mm_Vertical | https://cdn.amphenol-cs.com/media/wysiwyg/files/documentation/datasheet/boardwiretoboard/bwb_bergstik.pdf |  |  |  |  |  | Amphenol FCI | 67996-400HLF |  | 649-67996-400HLF | https://au.mouser.com/ProductDetail/Amphenol-FCI/67996-400HLF?qs=cpLrBgdhsoHypZ881pDXnQ%3D%3D | 1
J400 | PWR_JMP | Connector_PinHeader_2.54mm:PinHeader_1x02_P2.54mm_Vertical | https://cdn.amphenol-cs.com/media/wysiwyg/files/documentation/datasheet/boardwiretoboard/bwb_bergstik.pdf |  |  |  |  |  | Amphenol FCI | 67996-400HLF |  | 649-67996-400HLF | https://au.mouser.com/ProductDetail/Amphenol-FCI/67996-400HLF?qs=cpLrBgdhsoHypZ881pDXnQ%3D%3D | 1
J460 | -5V SELECT | Jumper:SolderJumper-3_P1.3mm_Bridged12_Pad1.0x1.5mm | ~ |  |  |  |  |  |  |  |  |  |  | 1
J500 | EXRAM | Jumper:SolderJumper-2_P1.3mm_Open_RoundedPad1.0x1.5mm | ~ |  |  |  |  |  |  |  |  |  |  | 1
J519, J520 | ROM_A19 | Connector_PinHeader_2.54mm:PinHeader_1x03_P2.54mm_Vertical | https://cdn.amphenol-cs.com/media/wysiwyg/files/documentation/datasheet/boardwiretoboard/bwb_econostik_254headers.pdf |  | Headers & Wire Housings 2.54MM VT ECONOSTIK HDR |  |  |  | Amphenol FCI | 10129378-903001BLF |  | 649-1012937890301BLF | https://au.mouser.com/ProductDetail/Amphenol-FCI/10129378-903001BLF?qs=0lQeLiL1qybuYTJnitumiA%3D%3D | 2
J650 | Z98 | Connector_PinHeader_2.54mm:PinHeader_1x03_P2.54mm_Vertical | https://cdn.amphenol-cs.com/media/wysiwyg/files/documentation/datasheet/boardwiretoboard/bwb_econostik_254headers.pdf |  | Headers & Wire Housings 2.54MM VT ECONOSTIK HDR |  |  |  | Amphenol FCI | 10129378-903001BLF |  | 649-1012937890301BLF | https://au.mouser.com/ProductDetail/Amphenol-FCI/10129378-903001BLF?qs=0lQeLiL1qybuYTJnitumiA%3D%3D | 1
J651 | Z97 | Connector_PinHeader_2.54mm:PinHeader_1x03_P2.54mm_Vertical | https://cdn.amphenol-cs.com/media/wysiwyg/files/documentation/datasheet/boardwiretoboard/bwb_econostik_254headers.pdf |  | Headers & Wire Housings 2.54MM VT ECONOSTIK HDR |  |  |  | Amphenol FCI | 10129378-903001BLF |  | 649-1012937890301BLF | https://au.mouser.com/ProductDetail/Amphenol-FCI/10129378-903001BLF?qs=0lQeLiL1qybuYTJnitumiA%3D%3D | 1
J900 | BGACK | Jumper:SolderJumper-2_P1.3mm_Bridged_RoundedPad1.0x1.5mm | ~ |  |  |  |  |  |  |  |  |  |  | 1
J950 | 14 MHz | Connector_PinHeader_2.54mm:PinHeader_1x02_P2.54mm_Vertical | https://cdn.amphenol-cs.com/media/wysiwyg/files/documentation/datasheet/boardwiretoboard/bwb_bergstik.pdf |  |  |  |  |  | Amphenol FCI | 67996-400HLF |  | 649-67996-400HLF | https://au.mouser.com/ProductDetail/Amphenol-FCI/67996-400HLF?qs=cpLrBgdhsoHypZ881pDXnQ%3D%3D | 1
J1201 | RED | Jumper:SolderJumper-2_P1.3mm_Open_RoundedPad1.0x1.5mm | ~ |  |  |  |  |  |  |  |  |  |  | 1
J1202 | GREEN | Jumper:SolderJumper-2_P1.3mm_Open_RoundedPad1.0x1.5mm | ~ |  |  |  |  |  |  |  |  |  |  | 1
J1203 | BLUE | Jumper:SolderJumper-2_P1.3mm_Open_RoundedPad1.0x1.5mm | ~ |  |  |  |  |  |  |  |  |  |  | 1
J1204 | VSYNC | Jumper:SolderJumper-2_P1.3mm_Open_RoundedPad1.0x1.5mm | ~ |  |  |  |  |  |  |  |  |  |  | 1
J1205 | HSYNC | Jumper:SolderJumper-2_P1.3mm_Open_RoundedPad1.0x1.5mm | ~ |  |  |  |  |  |  |  |  |  |  | 1
J1250 | PICLK | Jumper:SolderJumper-3_P1.3mm_Bridged12_RoundedPad1.0x1.5mm | ~ |  |  |  |  |  |  |  |  |  |  | 1
Q200, Q201 | MMBFJ309LT1G | SMD2000_Footprints:SOT96P237X111-3N | http://www.onsemi.com/pub/Collateral/MMBFJ309LT1-D.PDF |  | ON SEMICONDUCTOR - MMBFJ309LT1G - TRANSISTOR, JFET, N, 25V, SOT-23 |  | 1.11 | C58012 | onsemi | MMBFJ309LT1G |  | 863-MMBFJ309LT1G | https://www.mouser.co.uk/ProductDetail/onsemi/MMBFJ309LT1G?qs=HVbQlW5zcXXpftXEfcBAsg%3D%3D | 2
Q202, Q302, Q360-Q363 | MMBT3906LT3G | SMD2000_Footprints:SOT96P237X111-3N | http://www.onsemi.com/pub/Collateral/MMBT3906LT1-D.PDF |  | Transistor PNP 40V 200mA SOT-23 ON Semi MMBT3906LT3G PNP Bipolar Transistor, -800 mA -40 V, 3-Pin SOT-23 |  | 1.11 | C232602 | onsemi | MMBT3906LT3G |  | 863-MMBT3906LT3G | https://www.mouser.co.uk/ProductDetail/onsemi/MMBT3906LT3G?qs=HVbQlW5zcXX6Jyx0WYl8Eg%3D%3D | 6
Q300, Q301 | SMMBT3904LT1G | SMD2000_Footprints:SOT96P237X111-3N | https://www.onsemi.com/pub/Collateral/MMBT3904LT1-D.PDF |  | General Purpose Transistor NPN Silicon |  | 1.11 | C84555 | onsemi | SMMBT3904LT1G |  | 863-SMMBT3904LT1G | https://www.mouser.co.uk/ProductDetail/onsemi/SMMBT3904LT1G?qs=SHm1gYoUFFxP0E8RxmhUgw%3D%3D | 2
R104 | 4.7k | Resistor_SMD:R_0805_2012Metric_Pad1.20x1.40mm_HandSolder | https://www.yageo.com/upload/media/product/productsearch/datasheet/rchip/PYu-RC_Group_51_RoHS_L_11.pdf |  |  |  |  | C4279556 | Yageo | RC0805FR-104K7L |  | 603-RC0805FR-104K7L | https://au.mouser.com/ProductDetail/YAGEO/RC0805FR-104K7L?qs=m6lXFsvg5e3qsGC2wfapPw%3D%3D | 1
R105, R106 | 22 | Resistor_SMD:R_0805_2012Metric_Pad1.20x1.40mm_HandSolder | https://www.yageo.com/upload/media/product/productsearch/datasheet/rchip/PYu-RC_Group_51_RoHS_L_11.pdf |  | Thick Film Resistors - SMD 47 Ohms 125 mW 0805 5% |  | 0.6 | C108406 | YAGEO | RC0805JR-0722RL |  | 603-RC0805JR-0722RL | https://au.mouser.com/ProductDetail/YAGEO/RC0805JR-0722RL | 2
R109, R201, R300, R309, R362, R364, R500, R806, R807, R902, R916 | 4.7K | Resistor_SMD:R_0805_2012Metric_Pad1.20x1.40mm_HandSolder | https://www.yageo.com/upload/media/product/productsearch/datasheet/rchip/PYu-RC_Group_51_RoHS_L_11.pdf |  |  |  |  | C4279556 | Yageo | RC0805FR-104K7L |  | 603-RC0805FR-104K7L | https://au.mouser.com/ProductDetail/YAGEO/RC0805FR-104K7L?qs=m6lXFsvg5e3qsGC2wfapPw%3D%3D | 11
R110, R114, R115 | 330 | Resistor_SMD:R_0805_2012Metric_Pad1.20x1.40mm_HandSolder | https://www.yageo.com/upload/media/product/productsearch/datasheet/rchip/PYu-RC_Group_51_RoHS_L_11.pdf |  |  |  |  |  | Yageo | RC0805JR-10330RL |  | 603-RC0805JR-10330RL | https://au.mouser.com/ProductDetail/YAGEO/RC0805JR-10330RL?qs=fRxXYNj8ftElqNT0Ztj8ng%3D%3D | 3
R111, R801, R917, R1000 | 470 | Resistor_SMD:R_0805_2012Metric_Pad1.20x1.40mm_HandSolder | https://www.yageo.com/upload/media/product/productsearch/datasheet/rchip/PYu-RC_Group_51_RoHS_L_11.pdf |  |  |  |  | C4143257 | Yageo | RC0805JR-10470RL |  | 603-RC0805JR-10470RL | https://au.mouser.com/ProductDetail/YAGEO/RC0805JR-10470RL?qs=fRxXYNj8ftEFZlcbXaHWlw%3D%3D | 4
R200 | 1 | Resistor_SMD:R_0805_2012Metric_Pad1.20x1.40mm_HandSolder | https://www.yageo.com/upload/media/product/productsearch/datasheet/rchip/PYu-RC_Group_51_RoHS_L_11.pdf |  |  |  |  | C131397 | Yageo | RC0805FR-071RL |  | 603-RC0805FR-071RL | https://au.mouser.com/ProductDetail/YAGEO/RC0805FR-071RL?qs=8Y8p%252BasKcI5LWCyYnPKX0w%3D%3D | 1
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

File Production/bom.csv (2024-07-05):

Designator | Footprint | Quantity | Value | LCSC Part #
BT800 | S8411-45R_1 | 1 | CR1220 | C9900008699
C101, C222, C223, C402, C403, C404, C405, C406, C408, C412, C420, C421, C422, C471 | EEE0GA101SR | 14 | 47 uF | C178500
C102, C103, C104, C105, C106, C107, C108, C1201, C1202, C1203, C1204, C1205, C1251, C200, C202, C203, C205, C206, C230, C234, C240, C244, C300, C301, C302, C303, C305, C351, C360, C450, C451, C600, C601, C602, C603, C604, C605, C607, C800, C802, C803, C804, C805, C812, C815, C900, C901, C903, C906, C909, C910, C915, C916, C918, C919 | 0805 | 55 | 0.1 uF | C123316
C1206, C233, C243, C813, C814 | EEE0GA101SR | 5 | 22 uF | C336455
C1252, C908, C913 | 0805 | 3 | 47 pF | C2209271
C201, C219, C220, C221, C500, CE218 | 0805 | 6 | 0.22uF
C204, C401, C407, C409, C413, C472, CE310, CE325 | 0805 | 8 | 0.01 uF
C210, C211, C212, C213 | 0805 | 4 | 0.047 uF
C214, C225, C226, C912 | EEE-1EA471UAP | 4 | 470 uF | C336541
C224, C415, C811 | EEE1AA220WR | 3 | 4.7 uF | C336729
C231, C241, CE230, CE231, CE232, CE233, CE234, CE235, CE236, CE237 | 0805 | 10 | 6800 pF | C597425
C232, C242 | 0805 | 2 | 3900 pF | C2181318
C259, C260, C261, C904, C905, C907, C914, C920, CE300, CE301, CE302, CE303, CE304, CE305, CE306, CE307, CE308, CE309, CE326, CE328, CE333, CE335, CE336, CE337, CE338 | 0805 | 25 | 100 pF | C2167403
C350 | 0805 | 1 | 1 uF | C2167382
C400, C416, C470 | EEHZT1E331UP | 3 | 220 uF | C336328
C452 | 0805 | 1 | 4.7 uF
C617, C619, C620, C621, C622, C623, C624, C625, C626, C627, C628, C629, C630, C631, C632, C633, C635, C637, C639, C641, C645, C647, C649, C650, C651, C652, C654, C655, C657, C658, C659, C660, C661, C662, C663, C664, C665, C666, C667, C668, C669, C670, C671, C672, C673, C674, C678 | 0805 | 47 | 1000 pF | C2167121
C810 | 0805 | 1 | 18 pF | C2209310
CE238, CE239, CE240, CE241, CE242, CE243, CE327, CE329, CE330, CE331 | 0805 | 10 | 470 pF
CN101 | PinHeader_2x40_P2.54mm_Vertical | 1 | AGNUS BOARD
CN1201 | 1563315E | 1 | 15 Pin Video
CN1202 | PinHeader_1x08_P2.54mm_Vertical | 1 | ANALOGUE VIDEO
CN1250 | PinSocket_2x20_P2.54mm_Vertical | 1 | Raspberry Pi Zero
CN1251, CN1252 | PinHeader_1x02_P2.54mm_Vertical | 2 | PI BTN
CN201 | L717SDE09PA4CH3F | 1 | MOUSE
CN204 | RCJ2221 | 1 | AUDIO | C4991581
CN250 | PinHeader_2x05_P2.54mm_Vertical_Top_Bottom | 1 | JOYSTICK
CN251 | PinHeader_2x05_P2.54mm_Vertical_Top_Bottom | 1 | MOUSE
CN300 | SDF50J | 1 | KEYBOARD
CN301 | PinHeader_2x13_P2.54mm_Vertical | 1 | PARALLEL
CN303 | PinHeader_2x17_P2.54mm_Vertical | 1 | FLOPPY
CN305 | L717SDE09PA4CH3F | 1 | SERIAL
CN306 | PinHeader_1x03_P2.54mm_Vertical | 1 | POWER LED
CN350 | PinHeader_1x08_P2.54mm_Vertical | 1 | A500KBD
CN400 | 44206-0007_1 | 1 | POWER
CN450 | PinHeader_1x03_P2.54mm_Vertical | 1 | POWERSW
CN451, CN452, CN453 | PinHeader_1x03_P2.54mm_Vertical | 3 | 3.3 v
CN519, CN520 | PinHeader_1x02_P2.54mm_Vertical | 2 | A19_ROMSW
CN600 | TE_1-5530843-0 | 1 | CPU Card | C4693071
CN601 | TE_5645235-3 | 1 | Zorro | C4659716
CN606 | PinHeader_1x04_P2.54mm_Vertical | 1 | IPL
CN650 | PinHeader_1x07_P2.54mm_Vertical | 1 | CPU_EXT
CN950 | PinHeader_1x04_P2.54mm_Vertical | 1 | FLOPPY_EXT
D300, D353, D800, D801, D802 | SODFL2512X90N | 5 | 1N4148WS | C118873
D360 | LEDC2012X80N | 1 | BLUE | C9900019499
D803 | SOD2513X120N | 1 | BAT54WS | C124205
EMI200, EMI229 | W2H11A10184T1F | 2 | 100 pF
FB102, FB1201, FB1202, FB1203, FB1204, FB1205, FB301, FB302, FB303, FB401, FB907 | 1206 | 11 | FB | C6401928
HY200 | PinHeader_1x22_P2.54mm_Vertical | 1 | VIDIOT
J301 | PinHeader_1x02_P2.54mm_Vertical | 1 | DF1:
J351 | PinHeader_1x02_P2.54mm_Vertical | 1 | RESET
J400 | PinHeader_1x02_P2.54mm_Vertical | 1 | PWR_JMP
J500 | SolderJumper-2_P1.3mm_Open_RoundedPad1.0x1.5mm | 1 | EXRAM
J519, J520 | PinHeader_1x03_P2.54mm_Vertical | 2 | ROM_A19
J950 | PinHeader_1x02_P2.54mm_Vertical | 1 | 14 MHz
Q200, Q201 | SOT96P237X111-3N | 2 | MMBFJ309LT1G | C58012
Q202, Q302, Q360 | SOT96P237X111-3N | 3 | MMBT3906LT3G | C232602
Q300, Q301 | SOT96P237X111-3N | 2 | SMMBT3904LT1G | C84555
R1000, R111, R801, R917 | 0805 | 4 | 470 | C4143257
R104, R109, R201, R300, R309, R500, R806, R807, R902, R916, RP100.9 | 0805 | 11 | 4.7k | C4279556
R105, R106 | 0805 | 2 | 22 | C108406
R110, R114, R115 | 0805 | 3 | 330
R1201, R1202, R1203, R1204, R1205, R1206 | 0805 | 6 | 75 | C141697
R1207, R1208 | 0805 | 2 | 100
R1209, XRP1.1 | 0805 | 2 | 3.3K | C859147
R200 | 0805 | 1 | 1 | C131397
R203, R206, R214, R231, R232, R241, R242, R305, R306, R519, R520, R802, R804 | 0805 | 13 | 10K | C84376
R204, R205 | 0805 | 2 | 470K
R207, R208 | 0805 | 2 | 10 | C3944800
R209, R210 | 0805 | 2 | 1.2K | C4086736
R213, RP101.9 | 0805 | 2 | 2.7K | C4335714
R215, R914 | 1206 | 2 | 1 0.5W
R230, R240 | 0805 | 2 | 360R
R233, R243, R311, R312, R601, R602, R603, R810, R900, RP607.1, RP908.1 | 0805 | 11 | 1k | C95781
R234, R244 | 0805 | 2 | 390R
R307, R360, RE230, RE231, RE232, RE233, RE234, RE235, RE236, RE237, RE238, RE239, RE240, RE241, RE242, RE243, RE300, RE301, RE302, RE303, RE304, RE305, RE306, RE307, RE308, RE309, RE326, RE327, RE328, RE329, RE330, RE331, RE333, RE335, RE336, RE337, RE338, XR1 | 0805 | 38 | 68 | C137411
R351 | 0805 | 1 | 100 K | C4073370
R352, R451, R452, R453, R805 | 0805 | 5 | 47K
R904, R905, RE325, RP203.2, RP203.3 | 0805 | 5 | 47 | C114743
RE218 | 0805 | 1 | 4.7R | C137513
RE310 | 1210 | 1 | 47 0.5W | C718247
RP100, RP200, RP801, RP900, RP901, RP904, RP905 | EXBD10C102J | 7 | 4.7k x8 | C2654036
RP101 | EXBD10C102J | 1 | 2.7k x8 | C1731200
RP102, RP902, RP907 | CAY1647R0F4LF | 3 | 47Rx4
RP204 | CAY1647R0F4LF | 1 | 68R
RP205, RP301, RP601, RP602, RP603, RP604, RP605, RP606, RP800, RP903 | EXBD10C102J | 10 | 1k x8 | C1731193
RP300, RP600 | EXBD10C102J | 2 | 10k x8 | C278696
RP802 | CAY16-103J4LF | 1 | 1k | C784824
U102 | DIP-48_W15.24mm_Socket_LongPads | 1 | GARY
U103, U105 | SOIC127P1030X265-20N | 2 | SN74F245DWR | C7165
U104, U106 | SOIC127P1030X265-20N | 2 | SN74LS373DWR | C2867545
U107 | SOIC127P600X175-14N | 1 | SN74F04DR | C7159
U108 | SOIC127P600X175-14N | 1 | SN74LS74ADR | C39990
U1201 | SOIC127P600X175-8N | 1 | THS7316DRG4 | C2678439
U1202, U1203 | SOIC127P600X175-14N | 2 | SN74LVC86ADRG4
U1204, U1205 | SOP65P640X120-20N | 2 | SN74LVC574APWR | C7672
U1251, U351 | SOIC127P600X175-14N | 2 | SN74HCT14DR | C6769
U200 | DIP-48_W15.24mm_Socket_LongPads | 1 | PAULA
U201 | DIP-48_W15.24mm_Socket_LongPads | 1 | DENISE
U202 | SOIC127P600X175-16N | 1 | SN74LS157DR | C2653294
U203 | SOIC127P600X175-14N | 1 | SN74LS38DR | C7766
U204 | SOIC127P600X175-14N | 1 | LF347DR | C7917
U205 | SOIC127P1030X265-20N | 1 | SN74HCT244DWRG4
U206 | SOIC127P1030X265-20N | 1 | SN74HCT244DWRG4 | C3753563
U300, U301 | DIP-40_W15.24mm_Socket_LongPads | 2 | CIA
U302 | SOIC127P600X175-14N | 1 | SN74LS32DR | C116812
U303 | SOIC127P600X175-14N | 1 | SN74F08D | C2878688
U304 | SOIC127P600X175-14N | 1 | MAX1488ECSD+ | C2671966
U305 | SOIC127P600X175-14N | 1 | MAX1489ECSD+ | C1543802
U450 | SOIC127P780X200-8N | 1 | NE555PSR
U451 | SOT95P280X145-5N | 1 | SN74LVC1G04DBVR | C7827
U500 | DIP-42_W15.24mm_Socket_LongPads | 1 | ROM
U600, U601, U603, U604 | SOIC127P780X200-20N | 4 | SN74LS245NSR | C7753
U602, U605 | SOIC127P780X200-20N | 2 | SN74ALS245ANSR | C2675891
U607, U803 | SOIC127P600X175-14N | 2 | SN74LS08DR | C6802
U800 | DIP-48_W15.24mm_Socket_LongPads | 1 | BUSTER
U801 | DIP-18_W7.62mm_LongPads | 1 | MSM6242
U802 | SOIC127P600X175-16N | 1 | SN74LS138DR | C7736
U804 | SOIC127P600X175-16N | 1 | SN74LS148DR | C2674594
U805 | SOIC127P600X175-14N | 1 | LM339DR | C7948
U900 | SOIC127P600X175-14N | 1 | SN74F00DR | C7158
VC800 | JR500HV | 1 | 8-50pF
XC1 | 0805 | 1 | 270 pF | C2180917
Y800 | VT200F125PF20PPM | 1 | VT200F-32768 Hz

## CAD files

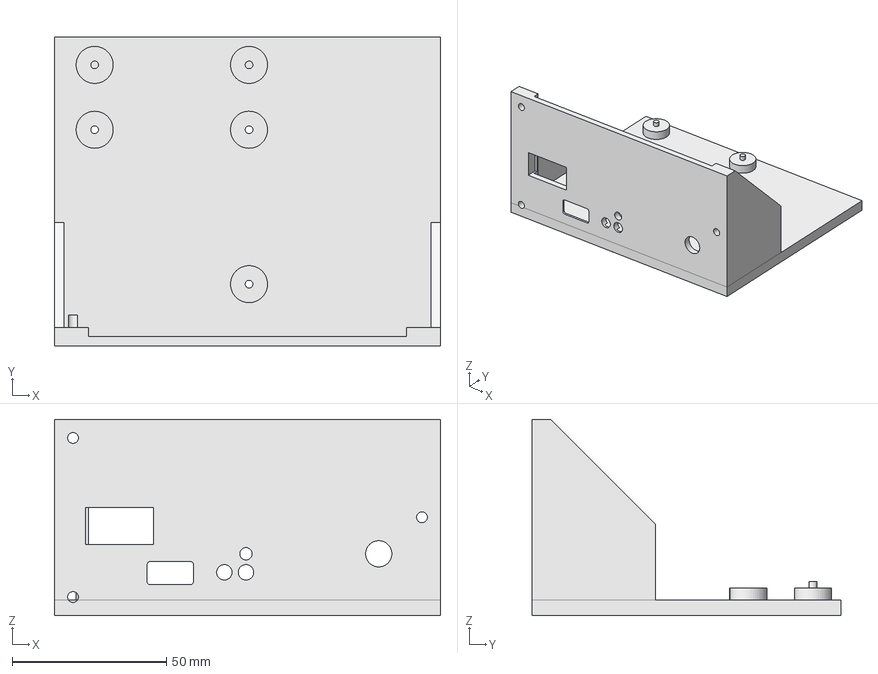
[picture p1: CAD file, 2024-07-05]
3d Prints/PSU Gotek Plate.FCStd
125.0 x 100.0 x 63.5 mm

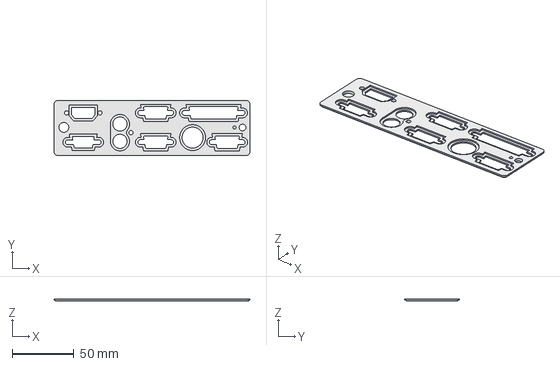
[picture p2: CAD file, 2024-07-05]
3d Prints/ioplate.FCStd
158.7 x 44.5 x 2.00 mm

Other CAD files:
3d Prints/PSU Gotek Plate.stl
3d Prints/ioplate.stl

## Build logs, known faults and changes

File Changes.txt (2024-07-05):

Changes from A2000 Rev6 Motherboard:
Page 1:
CPU has been removed, CPU only in CPU slot now.
7M & BG signals removed from this page.

Page 2:
CN250 and CN251 are internal headers for MOUSE and JOYSTICK ports.  Removed CN200 (JOYSTICK) for space.  MOUSE and SERIAL look identical, don't plug serial devices into the mouse port or you will fry something!
AUDIN and AUDOUT removed.
+5V rail instead of +5V_USER to power controller ports.  Controller port power changed to same as a1200 (4R7 and 0.22 uF).

Page 3:
Changed serial port to 9 pin DSUB.  Be careful not to plug the mouse in here or mouse will fry.
Serial and controller port filters changed to be same as A1200.
Removed "INFERNAL SERIAL" port.
Removed the AUDIN and AUDOUT lines, these are no longer useful without a modem.
Substituted Q300 2SC945 NPN transistor for 2N3904.
Added J351 header for case RESET_SW and a debounce circuit.
Added extra Power and FDD LED options.  Extra LED circuitry added since prototype made, untested but there is no reason they will not work.

Page 4:
+5V_USER, +12V_USER, -12V_USER have been omitted.  Ports fed from +5V rail instead.
Added optional -5V regulator in case the ATX PSU does not have a -5V rail (most likely won't need -5V anyhow).
Removed the TICK line, no TICK signal on ATX supply. The TICK input of U300 is connected to the _VSYNC line (like in the A500) see page 10.
J450 for case On/Off momentary push button switch.  U450 555 timer and U451 NOT gate toggle for the ATX PSU.  Powered from +5VSB.  
J400 grounds the #PS_ON signal (ATX pin 16) to start the PSU if using a toggle switch or a jumper during testing (effectively bypasses U450 & U451).

Page 5:
Chip ram moved to Agnus board.
Changed J500 to normally open by default (closed by default on A2000 and A500).  Close this jumper for 512 kb Agnus or if you want Ranger Ram instead of Chip Ram.
Modified ROM addressing to allow 1 MB custom roms to be addressed and use of larger EPROMS as kickstart switchers.

Page 6:
Removed all but first Zorro port and the CFGIN/CFGOUT logic.
Rearranged the resistor packs to make it easier for board layout.

Page 7:
Removed ISA bus entirely.  Bridgeboards are retarded.

Page 8:
Changed BT800 to CR1220 battery holder.  Replaced R308 with D308 schottky diode to prevent the computer from charging it (standard mod when replacing RTC batteries with coin cells).
Lines _EBG2 through _EBG5 go nowhere, they are only shown for completeness.

Page 9:
Agnus, ram control lines, and X1 28 MHz oscillator moved to Agnus card.  Replaced with 80 pin header.
Added J950 header for 14 MHz clock if it is generated on the Agnus card.
XCLK option has been removed.

Page 10:
TICK now connected to _VSYNC via J300 same as A500.  No provision for a PSU TICK signal.  If you need separate TICK cut J300 then solder a wire to pin 2.
Removed external FDD port and added header CN950 with signals only found on that port.
Changed parallel port to internal 26 pin header.  Parallel port EMI filtering same as A1200.
Added A500 keyboard port, primarily for a future USB adaptor but you can use A500 keyboard.

Page 11:
Removed Video Slot for space.
Changed RGB analogue output to buffered 15 pin "VGA" style socket.  Buffered RGB using THS7316DRG4.  Can by bypassed, don't install the THS7316DRG4 or resistors R1201-R1206, then bridge jumpers J1201-J1203.  To bypass the HSYNC & VSYNC buffer don't install R1207&R1208 then bridge J1204 & J1205.
Added internal header for (unbuffered) Analogue Video.  For future addition of SVideo via the AD723ARUZ PAL/NTSC encoder IC.
Added RGB2HDMI interface onboard.
EMI200 and EMI229 changed to SMD components since prototype; this change is untested but functionally identical.

Page 12:
Added header CN650, the CPU signals that are ordinarily on the CPU socket but not present on the CPU slot (plus E).

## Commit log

2024-07-05 Initial Release
    [BOM.csv, bom.csv, designators.csv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]
2024-07-05 Added section about power and 3d prints
